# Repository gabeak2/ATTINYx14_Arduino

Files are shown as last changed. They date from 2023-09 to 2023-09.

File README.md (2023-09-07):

# ATTINYx14_Arduino
An arduino-style breakout PCB for the ATTINY-x14 line of chips (specifically designed with the ATTINY1614).  Includes USB-Serial converter and USB connector so it is pretty much plug-and-play once you flash megatinycore onto it.



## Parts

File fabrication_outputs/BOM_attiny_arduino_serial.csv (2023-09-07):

Comment | Designator | Footprint | LCSC Part Number
10k | R4 | 805 | C17414
D_Small | D1 | SOD-123 | C8598
Crystal_GND24 | Y1 | 3225-4 | C9002
CH340G | U1 | SOIC-16_3.9x9.9mm_P1.27mm | C14267
4.7k | R3 | 805 | C17673
1k | R2,R1 | 805 | C17513
USB_B_Micro | J1 | USB_Micro-B_Molex-105017-0001 | C404969
100n | C7,C4,C2 | 805 | C49678
22p | C6,C5 | 805 | C1804
22u | C3 | 805 | C45783
1n | C1 | 805 | C46653

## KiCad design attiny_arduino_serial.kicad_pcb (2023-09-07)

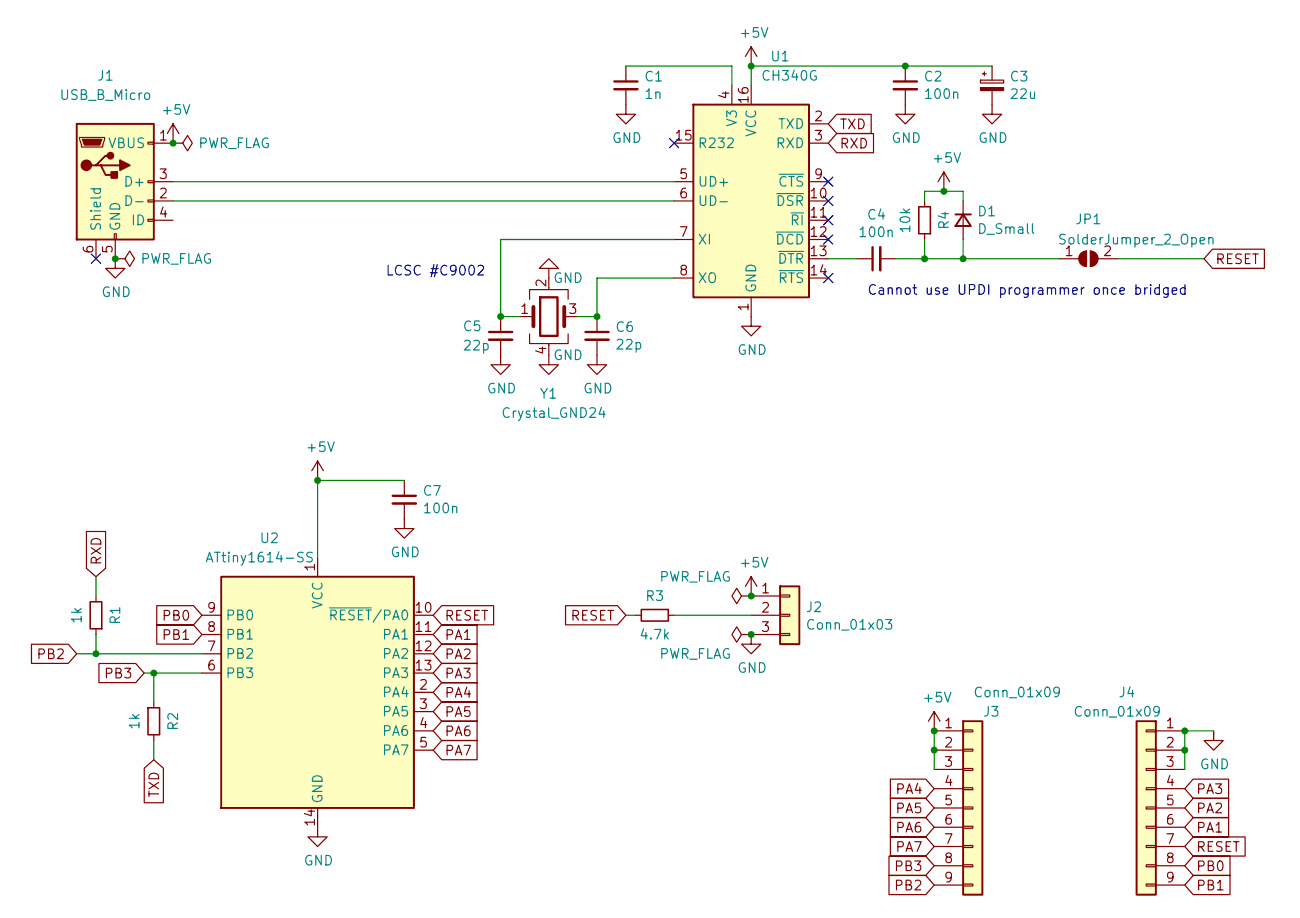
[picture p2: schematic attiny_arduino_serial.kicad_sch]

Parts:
C1: 1n; C_0805_2012Metric_Pad1.18x1.45mm_HandSolder
C2, C4, C7: 100n; C_0805_2012Metric_Pad1.18x1.45mm_HandSolder
C3: 22u; C_0805_2012Metric_Pad1.18x1.45mm_HandSolder
C5, C6: 22p; C_0805_2012Metric_Pad1.18x1.45mm_HandSolder
D1: D_Small; D_SOD-123
J1: USB_B_Micro; USB_Micro-B_Molex-105017-0001
J2: Conn_01x03; PinSocket_1x03_P2.54mm_Vertical
J3, J4: Conn_01x09; PinSocket_1x09_P2.54mm_Vertical
JP1: SolderJumper_2_Open; SolderJumper-2_P1.3mm_Open_Pad1.0x1.5mm
R1, R2: 1k; R_0805_2012Metric_Pad1.20x1.40mm_HandSolder
R3: 4.7k; R_0805_2012Metric_Pad1.20x1.40mm_HandSolder
R4: 10k; R_0805_2012Metric_Pad1.20x1.40mm_HandSolder
U1: CH340G; SOIC-16_3.9x9.9mm_P1.27mm
U2: ATtiny1614-SS; SOIC-14_3.9x8.7mm_P1.27mm
Y1: Crystal_GND24; Crystal_SMD_3225-4Pin_3.2x2.5mm_HandSoldering

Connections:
+5V: C2.1, C3.1, C7.1, D1.1 (K), J1.1 (VBUS), J2.1, J3.1, J3.2, J3.3, R4.2, U1.16 (VCC), U2.1 (VCC)
GND: C1.2, C2.2, C3.2, C5.2, C6.2, C7.2, J1.5 (GND), J2.3, J4.1, J4.2, J4.3, U1.1 (GND), U2.14 (GND), Y1.2, Y1.4
unnamed: C1.1, U1.4 (V3)
unnamed: C4.1, U1.13 (~DTR)
unnamed: C4.2, D1.2 (A), JP1.1 (A), R4.1
unnamed: C5.1, U1.7 (XI), Y1.1
unnamed: C6.1, U1.8 (XO), Y1.3
unnamed: J1.2 (D-), U1.6 (UD-)
unnamed: J1.3 (D+), U1.5 (UD+)
unnamed: J2.2, R3.1
PA1: J4.6, U2.11 (PA1)
PA2: J4.5, U2.12 (PA2)
PA3: J4.4, U2.13 (PA3)
PA4: J3.4, U2.2 (PA4)
PA5: J3.5, U2.3 (PA5)
PA6: J3.6, U2.4 (PA6)
PA7: J3.7, U2.5 (PA7)
PB0: J4.8, U2.9 (PB0)
PB1: J4.9, U2.8 (PB1)
PB2: J3.9, R1.1, U2.7 (PB2)
PB3: J3.8, R2.1, U2.6 (PB3)
RESET: J4.7, JP1.2 (B), R3.2, U2.10 (~RESET/PA0)
RXD: R1.2, U1.3 (RXD)
TXD: R2.2, U1.2 (TXD)

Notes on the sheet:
LCSC #C9002
Cannot use UPDI programmer once bridged

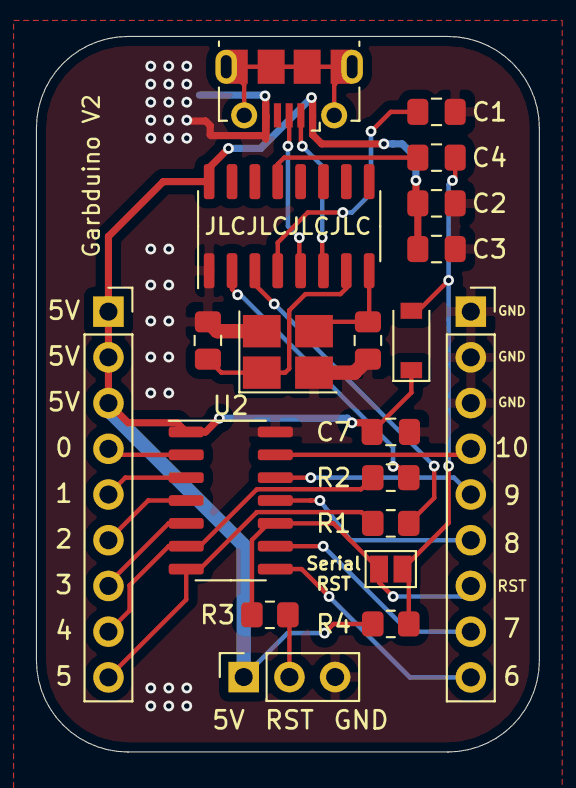
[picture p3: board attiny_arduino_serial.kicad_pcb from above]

Board: 2 copper layers, 27.9 x 39.8 mm, 20 parts (0 on the bottom side), 24 nets.
